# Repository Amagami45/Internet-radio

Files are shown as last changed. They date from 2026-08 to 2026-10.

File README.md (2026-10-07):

# Internet-radio

This project is about building an internet radio receiver which will change the audio output to analog, which will be transferred to an old FM radio (AIWA). From the radio, audio will come out to connected speakers.

## Why?

I have an old Aiwa, which can do only FM and AM frequencies, and most radio stations start to turn to DAB+ signal. So that's the main reason why I chose building this internet radio receiver. Also, I can listen to foreign countries' radio stations.

## Technical specifications

It's powered by a USB-C 16-pin connector (5V). Then it's reduced to 3.3V by AMS1117 regulator. Most parts use 3.3V logic.

### Display
* 2.8" SPI TFT display (ILI9341 controller, 240x320). Connected via cables to the PCB.

### Buttons & Controls
I used Cherry MX switches and a rotary encoder:
* Reset button
* Sleep / ON button
* Up button
* Down button
* Rotary encoder – Volume up / Volume down
* Rotary encoder button – Sound off (Mute)

### Audio output
It's done by PCM5102A DAC chip (I2S audio interface) and 2 RCA cinches (Stereo Left/Right), which connect directly to AIWA AUX input.

## BOM (Bill of Materials)

* ESP32-WROOM-32 (with Bluetooth and Wi-Fi)
* PCM5102A DAC board/chip
* 2.8" SPI TFT Display (ILI9341)
* USB-C 16-pin connector (Type-C)
* AMS1117 3.3V LDO regulator
* Dual horizontal RCA cinch connector
* Cherry MX mechanical switches
* Rotary encoder
* 0603 SMD capacitors and resistors

## Schematics & PCB Design

I used KiCad for that (2-layer board design). Display will be connected by cables, that's why it is designed like it is. 

Snímek obrazovky 2026-08-31 152727
Snímek obrazovky 2026-08-17 105338

## 3D PCB & Case Renders

* 3D PCB export (.STEP) is generated from KiCad.
* All other parts and enclosure case are modeled in Fusion 360.

Snímek obrazovky 2026-08-31 153812
Snímek obrazovky 2026-08-31 153729
Snímek obrazovky 2026-09-01 002420

## 3D Printing Settings

* **Material:** PETG (recommended) or PLA
* **Layer Height:** 0.2 mm
* **Infill:** 15–20% (Gyroid or Grid)
* **Supports:** Needed only for RCA and USB-C cutouts on the rear panel

## Assembly Guide

### 1. PCB Assembly & Soldering
1. **SMD Components First:** Solder the small SMD parts first (AMS1117 regulator, 0603 capacitors/resistors, USB-C connector, and PCM5102A DAC).
2. **ESP32 Module:** Align and solder the ESP32-WROOM-32 module onto the board.
3. **Through-Hole Parts (THT):** Solder the Cherry MX switches, rotary encoder, and dual RCA cinch connector.

### 2. Display Wiring
* Connect the 2.8" ILI9341 TFT display to the PCB header using cables according to the KiCad schematic (VCC, GND, CS, RESET, DC, SDI/MOSI, SCK, LED).

### 3. Firmware Flashing
1. Connect the board to your PC via USB-C.
2. Flash **YoRadio** firmware using PlatformIO / Arduino IDE / Esptool.
3. Configure your GPIO pin mappings for the display, I2S DAC, rotary encoder, and Cherry MX buttons in `myoptions.h`.
4. Connect to the radio's Wi-Fi Access Point to set up your home Wi-Fi credentials and station playlist.

### 4. Enclosure Assembly
1. 3D print the case parts designed in Fusion 360.
2. Mount the 2.8" TFT display into the front panel slot.
3. Secure the PCB inside the main case using small M2/M3 screws.
4. Press keycaps onto the Cherry MX switches and attach the knob to the rotary encoder.
5. Close the 3D-printed enclosure.

### 5. Hooking up to AIWA
1. Connect an RCA stereo audio cable from the radio's cinch connectors to the **AUX / Line In** on your AIWA system.
2. Plug in a standard 5V USB-C power source.
3. Turn on AIWA, switch mode to AUX, select your favorite station, and enjoy!

# Pinout & Connections

## 1. ILI9341 Display (U4)
| ILI9341 Display | ESP32 (U1) / Power | Note |
| :--- | :--- | :--- |
| **VCC** | +3.3V | Logic / Display Power |
| **GND** | GND | Ground |
| **CS** | **IO0** (DISP_CS) | Display Chip Select |
| **D/C** | **IO16** (D/C) | Data / Command |
| **MOSI** | **IO23** | SPI MOSI |
| **MISO** | **IO19** | SPI MISO |
| **SCK** | **IO18** | SPI Clock |
| **LED** | **IO17** (LED) | Backlight Control |
| **RESET** | **RESET** (via D/C / RESET network) | Display Reset |

---

## 2. Micro SD Card Slot (J2)
| Micro SD Slot | Power Source / ESP32 (U1) | Note |
| :--- | :--- | :--- |
| **VDD (Pin 4)** | +3.3V | SD Card Power |
| **GND (Pin 3, 6)** | GND | Ground |
| **DAT3/CD (Pin 2)** | **IO12** (SD_CS) / **IO5** | Chip Select (10kΩ pull-up R6) |
| **CMD (Pin 3)** | **IO23** | SPI MOSI |
| **CLK (Pin 5)** | **IO18** | SPI SCK |
| **DAT0 (Pin 7)** | **IO19** | SPI MISO (10kΩ pull-up R16) |
| **DAT1 (Pin 8)** | — | 10kΩ pull-up R17 to +3.3V |
| **DAT2 (Pin 1)** | — | 10kΩ pull-up R15 to +3.3V |

---

## 3. Audio DAC PCM5102 (U3)
| PCM5102 Pin | ESP32 (U1) / Power | Function / Note |
| :--- | :--- | :--- |
| **CPVDD, DVDD, AVDD** | +3.3V | DAC Power (filtered by C3, C4, C5) |
| **GND, AGND, DGND** | GND | Ground |
| **LRCK (Pin 15)** | **IO25** | I2S Word Select (LRCK) |
| **DIN (Pin 14)** | **IO27** | I2S Data Input |
| **BCK (Pin 13)** | **IO26** | I2S Bit Clock |
| **SCK (Pin 12)** | GND | System Clock (connected to GND) |
| **OUTL (Pin 6)** | C3 / R5 / J3A Output | Left Channel Audio Output (Coaxial J3A) |
| **OUTR (Pin 7)** | C1 / R4 / J3B Output | Right Channel Audio Output (Coaxial J3B) |

---

## 4. Rotary Encoder with Button (SW1)
| Encoder Pin | ESP32 (U1) / Power | Note |
| :--- | :--- | :--- |
| **A (Pin A)** | **IO32** | Encoder Phase A |
| **B (Pin B)** | **IO33** | Encoder Phase B |
| **C (Pin C)** | GND | Encoder Common Pin |
| **S1 (Pin S1)** | **IO18** | Encoder Switch / Button |
| **S2 (Pin S2)** | GND | Encoder Switch Other Side |

---

## 5. Control Buttons
| Button | ESP32 Pin | Connection |
| :--- | :--- | :--- |
| **SW2** | **IO23** / **IO5** | Pushbutton to GND (switches to GND) |
| **SW3** | **IO22** | Pushbutton to GND (switches to GND) |
| **SW5** | **IO15** (via 1kΩ R12) | Pushbutton to GND (switches to GND) |
| **SW6** | **EN** | RESET button (switches EN to GND) |
| **SW7** | **IO3 (RXD)** (via R8/R11) | User / Boot Button |

---

## 6. USB-C UART Converter (CP2102N - U5) & Power Supply
* **USB Connector (J1):** Supplies VBUS (+5V) to the **AMS1117-3.3 (U2)** regulator, which generates the main **+3.3V** power supply for the entire circuit.
* **Converter CP2102N (U5):**
  * **TXD (Pin 21)** $\rightarrow$ **IO3 (RXD)** on ESP32 (via 1kΩ resistor R11)
  * **RXD (Pin 20)** $\leftarrow$ **IO1 (TXD)** from ESP32 (via 1kΩ resistor R12)
  * **DTR / RTS** $\rightarrow$ Connected to **Q1/Q2 (BC847)** transistors for automatic programming mode switching (EN and IO0).

## Software & Firmware

The radio firmware is built on the **ESP32** platform (Arduino IDE / PlatformIO) and ensures smooth reception of internet streams via Wi-Fi, their decoding, and digital audio processing.

### Key Features
* **Wi-Fi Connectivity:** Automatic connection to the configured network at system startup.
* **Audio Streaming (I2S):** Direct digital audio data transmission over the I2S interface to the PCM5102 DAC for high sound quality.
* **Station Management:** Pre-configured playlist of domestic and foreign radio stations (MP3/AAC streams) with sequential switching.
* **Volume Control:** Fine digital volume control directly inside the audio decoder.

### Control Mapping
Control is handled via buttons and a rotary encoder connected to the ESP32 GPIO pins:
* **SW3 (BTN_UP):** Switch to the next radio station.
* **SW2 (BTN_DOWN):** Switch to the previous radio station.
* **SW5 (BTN_LEFT):** Volume down.
* **SW7 (BTN_RIGHT):** Volume up.
* **SW1 (Encoder):** Menu navigation and additional features.

### Included Libraries
* **WiFi.h** – Network connection and wireless management.
* **ESP32-audioI2S** – Audio decoding and I2S communication handling.

## Credits & Acknowledgments

* Firmware powered by **ESP32-audioI2S** and **WiFi.h** library.

## License

This work is under GNU license. More info in LICENSE file.

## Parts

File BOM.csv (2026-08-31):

No | Quantity | Comment | Designator | Footprint | Value | Manufacturer Part | Manufacturer | Supplier Part | Supplier | Price | URL
1 | 1 | ESP32 Wi-Fi/BT Module | U1 | RF_Module:ESP32-WROOM-32 | ESP32-WROOM-32 | ESP32-WROOM-32E-N4 | Espressif | C473012 | LCSC | 2.85$ | https://www.lcsc.com/product-detail/WiFi-Modules_Espressif-Systems-ESP32-WROOM-32E-N4_C473012.html
2 | 1 | 3.3V LDO Voltage Regulator | U2 | Package_TO_SOT_SMD:SOT-223-3_TabPin2 | AMS1117-3.3 | AMS1117-3.3 | AMS | C6186 | LCSC | 0.12$ | https://www.lcsc.com/product-detail/Linear-Voltage-Regulators-LDO_AMS-Advanced-Monolithic-Systems-AMS1117-3-3_C6186.html
3 | 1 | I2S Audio DAC Chip | U3 | Package_SO:TSSOP-20_4.4x6.5mm_P0.65mm | PCM5102A | PCM5102AIPWR | Texas Instruments | C67139 | LCSC | 1.80$ | https://www.lcsc.com/product-detail/Audio-Processors-DACS-MDS_Texas-Instruments-PCM5102AIPWR_C67139.html
4 | 1 | TFT Display Screen | U4 | Display:CR2013-MI2120 | CR2013-MI2120 | CR2013-MI2120 | Generic | Custom | AliExpress | 2.50$ | http://pan.baidu.com/s/11Y990
5 | 1 | USB-to-UART Bridge | U5 | Package_DFN_QFN:QFN-24-1EP_4x4mm_P0.5mm_EP2.6x2.6mm | CP2102N-Axx-xQFN24 | CP2102N-A02-GQFN24R | Silicon Labs | C141118 | LCSC | 1.20$ | https://www.lcsc.com/product-detail/USB-IC_Silicon-Labs-CP2102N-A02-GQFN24R_C141118.html
6 | 2 | NPN Transistor | Q1, Q2 | Package_TO_SOT_SMD:SOT-23 | BC847 | BC847B | Nexperia | C2131 | LCSC | 0.02$ | https://www.lcsc.com/product-detail/Bipolar-Transistors-BJT_Nexperia-BC847B-215_C2131.html
7 | 1 | USB-C Receptacle 16P | J1 | Connector_USB:USB_C_Receptacle_HRO_TYPE-C-31-M-12 | TYPE-C 16PIN 2MD(073) | TYPE-C 16PIN 2MD(073) | SHOU HAN | C2765186 | LCSC | 0.08$ | https://www.lcsc.com/product-detail/C2765186.html
8 | 1 | Micro SD Card Slot | J2 | Connector_Card:microSD_HC_Hirose_DM3AT-SF-PEJM5 | Micro_SD_Card | DM3AT-SF-PEJM5 | Hirose | C114219 | LCSC | 0.40$ | https://www.we-online.com/components/products/datasheet/693072010801.pdf
9 | 1 | 4-Pin Header (Audio Out) | J3 | Connector_PinHeader_2.54mm:PinHeader_1x04_P2.54mm_Vertical | Conn_Coaxial_x2_Isolated | Header-1x4P-2.54 | Generic | C22548 | LCSC | 0.05$ | https://www.lcsc.com/product-detail/Pin-Header-Female-Header_C22548.html
10 | 1 | Rotary Encoder with Switch | SW1 | Rotary_Encoder:RotaryEncoder_Alps_EC11E-Switch_Vertical_H20mm | RotaryEncoder_Switch | EC11E1224404 | ALPS | C25243 | LCSC | 0.50$ | https://www.lcsc.com/product-detail/Encoders_ALPS-EC11E1224404_C25243.html
11 | 5 | Cherry MX Push Switch | SW2, SW3, SW5, SW6, SW7 | Button_Switch_Keyboard:SW_Cherry_MX_1.00u_PCB | SW_Push | MX-1.0U | Cherry | Custom | AliExpress | 0.25$ | https://www.aliexpress.com
12 | 2 | 5.1k Resistor 0603 | R1, R2 | Resistor_SMD:R_0603_1608Metric | 5.1k | 0603WAF5101T5E | UNI-ROYAL | C23186 | LCSC | 0.005$ | https://www.lcsc.com/product-detail/C23186.html
13 | 10 | 10k Resistor 0603 | R3, R6, R7, R8, R10, R13, R14, R15, R16, R17 | Resistor_SMD:R_0603_1608Metric | 10k | 0603WAF1002T5E | UNI-ROYAL | C25804 | LCSC | 0.005$ | https://www.lcsc.com/product-detail/Chip-Resistor-Surface-Mount_UNI-ROYAL-Uni-Royal-Elec-0603WAF1002T5E_C25804.html
14 | 2 | 470R Resistor 0603 | R4, R5 | Resistor_SMD:R_0603_1608Metric | 470R | 0603WAF4700T5E | UNI-ROYAL | C23179 | LCSC | 0.005$ | https://www.lcsc.com/product-detail/Chip-Resistor-Surface-Mount_UNI-ROYAL-Uni-Royal-Elec-0603WAF4700T5E_C23179.html
15 | 1 | 4.7k Resistor 0603 | R9 | Resistor_SMD:R_0603_1608Metric | 4.7k | 0603WAF4701T5E | UNI-ROYAL | C23162 | LCSC | 0.005$ | https://www.lcsc.com/product-detail/Chip-Resistor-Surface-Mount_UNI-ROYAL-Uni-Royal-Elec-0603WAF4701T5E_C23162.html
16 | 2 | 1k Resistor 0603 | R11, R12 | Resistor_SMD:R_0603_1608Metric | 1k | 0603WAF1001T5E | UNI-ROYAL | C21190 | LCSC | 0.005$ | https://www.lcsc.com/product-detail/Chip-Resistor-Surface-Mount_UNI-ROYAL-Uni-Royal-Elec-0603WAF1001T5E_C21190.html
17 | 2 | 2.2uF Capacitor 0603 | C1, C6 | Capacitor_SMD:C_0603_1608Metric | 2.2uF | CL10A225KP8NNNC | SAMSUNG | C15858 | LCSC | 0.01$ | https://www.lcsc.com/product-detail/Multilayer-Ceramic-Capacitors-MLCC-SMD-SMT_SAMSUNG-CL10A225KP8NNNC_C15858.html
18 | 2 | 1uF Capacitor 0603 | C2, C7 | Capacitor_SMD:C_0603_1608Metric | 1uF | CL10A105KB8NNNC | SAMSUNG | C15849 | LCSC | 0.01$ | https://www.lcsc.com/product-detail/C15849.html
19 | 9 | 100nF Capacitor 0603 | C3, C4, C5, C9, C11, C12, C13, C19, C20 | Capacitor_SMD:C_0603_1608Metric | 100nF | CL10B104KB8NNNC | SAMSUNG | C14663 | LCSC | 0.005$ | https://www.lcsc.com/product-detail/Multilayer-Ceramic-Capacitors-MLCC-SMD-SMT_SAMSUNG-CL10B104KB8NNNC_C14663.html
20 | 2 | 10uF Capacitor 0603 | C8, C10 | Capacitor_SMD:C_0603_1608Metric | 10uF | CL10A106MO8NNNC | SAMSUNG | C19702 | LCSC | 0.02$ | https://www.lcsc.com/product-detail/Multilayer-Ceramic-Capacitors-MLCC-SMD-SMT_SAMSUNG-CL10A106MO8NNNC_C19702.html
21 | 2 | 2.2nF Capacitor 0603 | C14, C15 | Capacitor_SMD:C_0603_1608Metric | 2.2nF | CL10B222KB8NNNC | SAMSUNG | C1600 | LCSC | 0.005$ | https://www.lcsc.com/product-detail/Multilayer-Ceramic-Capacitors-MLCC-SMD-SMT_SAMSUNG-CL10B222KB8NNNC_C1600.html
22 | 2 | 4.7uF Capacitor 0603 | C18, C21 | Capacitor_SMD:C_0603_1608Metric | 4.7uF | CL10A475KP8NNNC | SAMSUNG | C19666 | LCSC | 0.01$ | https://www.lcsc.com/product-detail/Multilayer-Ceramic-Capacitors-MLCC-SMD-SMT_SAMSUNG-CL10A475KP8NNNC_C19666.html

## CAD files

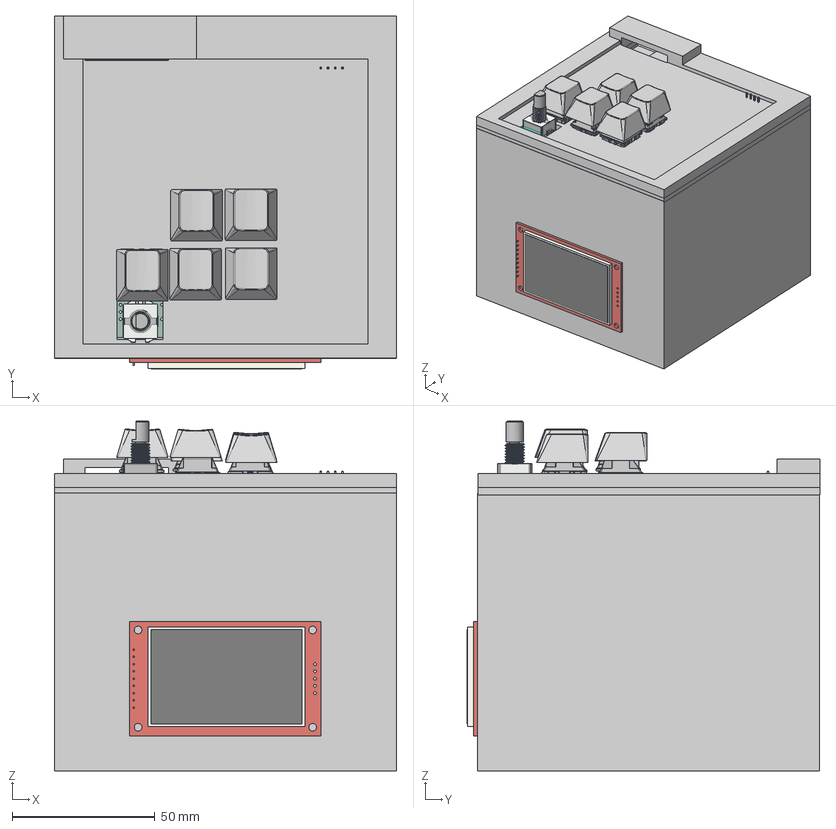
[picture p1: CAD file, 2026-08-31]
3d aiwa model 1.step
120.0 x 123.8 x 122.7 mm

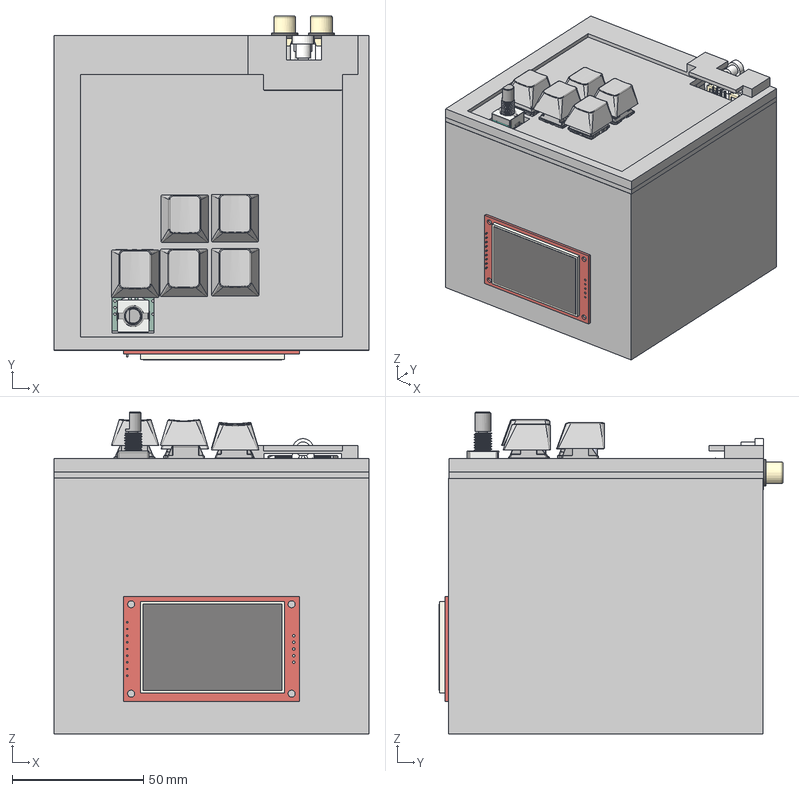
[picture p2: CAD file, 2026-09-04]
3d aiwa/3d aiwa model.step
120.0 x 131.2 x 122.7 mm

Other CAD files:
3d aiwa/3d aiwa model.f3z
3d aiwa/3d aiwa model.stl
3d aiwa/Aiwa up.f3d
3d aiwa/Aiwa.f3d

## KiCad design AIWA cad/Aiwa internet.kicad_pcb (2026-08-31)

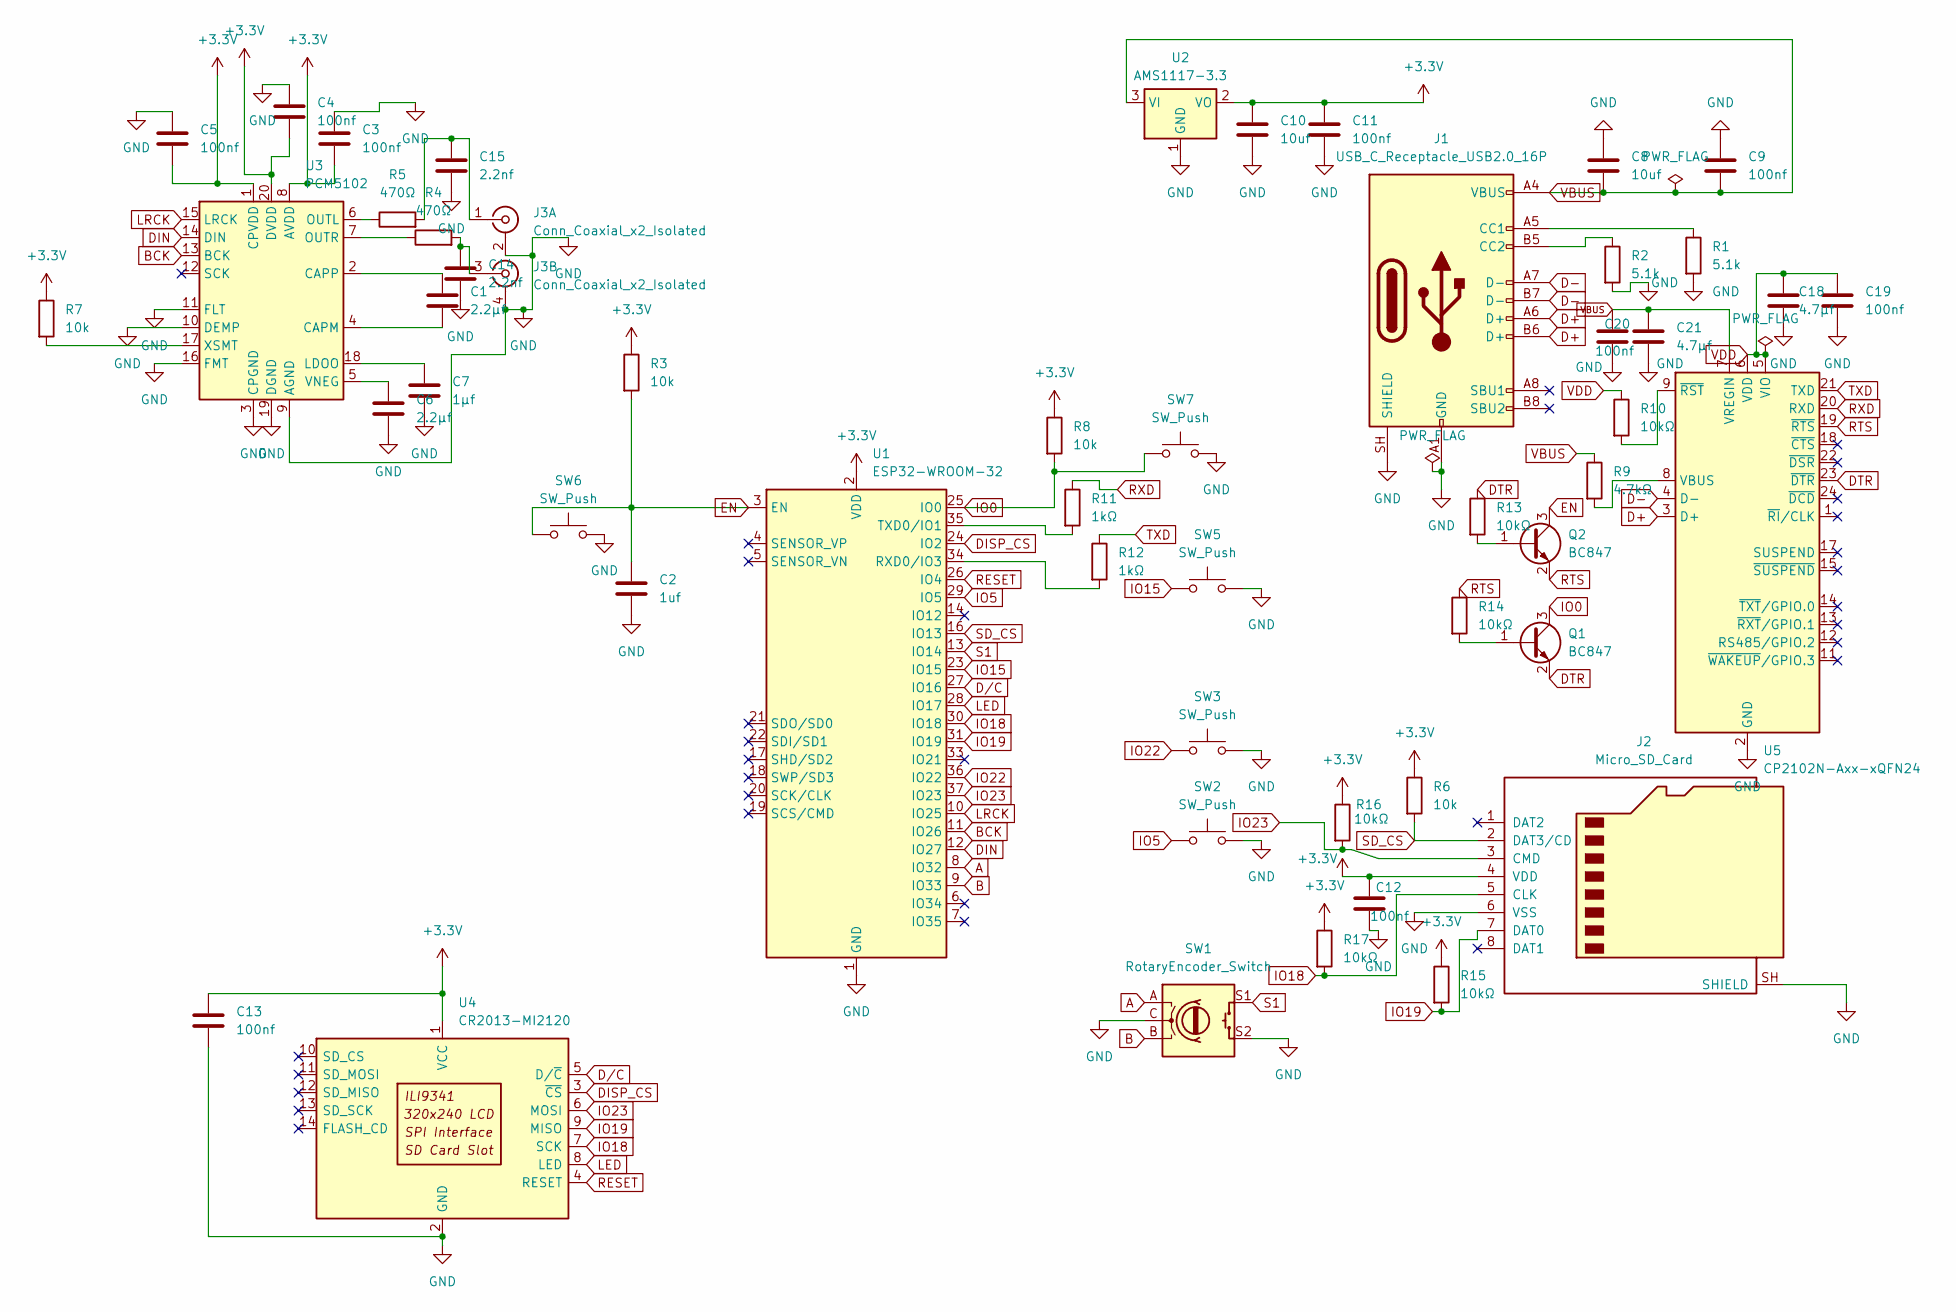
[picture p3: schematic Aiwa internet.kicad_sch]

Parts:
C1, C6: 2.2μf; C_0603_1608Metric
C2: 1uf; C_0603_1608Metric
C3, C4, C5, C9, C11, C12, C13, C19, C20: 100nf; C_0603_1608Metric
C7: 1μf; C_0603_1608Metric
C8, C10: 10uf; C_0603_1608Metric
C14, C15: 2.2nf; C_0603_1608Metric
C18, C21: 4.7µf; C_0603_1608Metric
J1: USB_C_Receptacle_USB2.0_16P; USB_C_Receptacle_HRO_TYPE-C-31-M-12
J2: Micro_SD_Card; microSD_HC_Hirose_DM3AT-SF-PEJM5
J3: Conn_Coaxial_x2_Isolated; PinHeader_1x04_P2.54mm_Vertical
Q1, Q2: BC847; SOT-23
R1, R2: 5.1k; R_0603_1608Metric
R3, R6, R7, R8: 10k; R_0603_1608Metric
R4, R5: 470Ω; R_0603_1608Metric
R9: 4.7kΩ; R_0603_1608Metric
R10, R13, R14, R15, R16, R17: 10kΩ; R_0603_1608Metric
R11, R12: 1kΩ; R_0603_1608Metric
SW1: RotaryEncoder_Switch; RotaryEncoder_Alps_EC11E-Switch_Vertical_H20mm
SW2, SW3, SW5, SW6, SW7: SW_Push; SW_Cherry_MX_1.00u_PCB
U1: ESP32-WROOM-32
U2: AMS1117-3.3; SOT-223-3_TabPin2
U3: PCM5102; TSSOP-20_4.4x6.5mm_P0.65mm
U4: CR2013-MI2120
U5: CP2102N-Axx-xQFN24; QFN-24-1EP_4x4mm_P0.5mm_EP2.6x2.6mm

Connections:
+3.3V: C3.2, C4.2, C5.2, C10.1, C11.1, C12.1, C13.1, J2.4 (VDD), R3.1, R6.1, R7.1, R8.1, R15.1, R16.1, R17.1, U1.2 (VDD), U2.2 (VO), U3.1 (CPVDD), U3.8 (AVDD), U3.20 (DVDD), U4.1 (VCC)
A: SW1.A, U1.8 (IO32)
B: SW1.B, U1.9 (IO33)
BCK: U1.11 (IO26), U3.13 (BCK)
D+: J1.A6 (D+), J1.B6 (D+), U5.3 (D+)
D-: J1.A7 (D-), J1.B7 (D-), U5.4 (D-)
DIN: U1.12 (IO27), U3.14 (DIN)
DISP_CS: U1.24 (IO2), U4.3 (~CS)
DTR: Q1.2 (E), R13.1, U5.23 (~DTR)
D/C: U1.27 (IO16), U4.5 (D/~C)
EN: C2.1, Q2.3 (C), R3.2, SW6.1, U1.3 (EN)
GND: C2.2, C3.1, C4.1, C5.1, C6.2, C7.2, C8.1, C9.1, C10.2, C11.2, C12.2, C13.2, C14.2, C15.2, C18.2, C19.2, C20.2, C21.2, J1.A1 (GND), J1.A12 (GND), J1.B1 (GND), J1.B12 (GND), J1.SH (SHIELD), J2.6 (VSS), J2.SH (SHIELD), J3.2 (Ext1), J3.4 (Ext2), R1.2, R2.2, SW1.C, SW1.S2, SW2.2, SW3.2, SW5.2, SW6.2, SW7.2, U1.1 (GND), U1.15 (GND), U1.38 (GND), U1.39 (GND), U2.1 (GND), U3.3 (CPGND), U3.9 (AGND), U3.10 (DEMP), U3.11 (FLT), U3.16 (FMT), U3.19 (DGND), U4.2 (GND), U5.2 (GND), U5.25 (GND)
IO0: Q1.3 (C), R8.2, SW7.1, U1.25 (IO0)
IO5: SW2.1, U1.29 (IO5)
IO15: SW5.1, U1.23 (IO15)
IO18: J2.5 (CLK), R17.2, U1.30 (IO18), U4.7 (SCK)
IO19: J2.7 (DAT0), R15.2, U1.31 (IO19), U4.9 (MISO)
IO22: SW3.1, U1.36 (IO22)
IO23: J2.3 (CMD), R16.2, U1.37 (IO23), U4.6 (MOSI)
LED: U1.28 (IO17), U4.8 (LED)
LRCK: U1.10 (IO25), U3.15 (LRCK)
unnamed: J1.A5 (CC1), R1.1
unnamed: J1.B5 (CC2), R2.1
unnamed: C15.1, J3.1 (In1), R5.2
unnamed: C14.1, J3.3 (In2), R4.2
unnamed: Q1.1 (B), R14.2
unnamed: Q2.1 (B), R13.2
unnamed: R12.2, U1.34 (RXD0/IO3)
unnamed: R11.2, U1.35 (TXD0/IO1)
unnamed: C1.2, U3.4 (CAPM)
unnamed: C1.1, U3.2 (CAPP)
unnamed: C7.1, U3.18 (LDOO)
unnamed: R5.1, U3.6 (OUTL)
unnamed: R4.1, U3.7 (OUTR)
unnamed: C6.1, U3.5 (VNEG)
unnamed: R7.2, U3.17 (XSMT)
unnamed: R9.2, U5.8 (VBUS)
unnamed: R10.2, U5.9 (~RST)
RESET: U1.26 (IO4), U4.4 (RESET)
RTS: Q2.2 (E), R14.1, U5.19 (~RTS)
RXD: R11.1, U5.20 (RXD)
S1: SW1.S1, U1.13 (IO14)
SD_CS: J2.2 (DAT3/CD), R6.2, U1.16 (IO13)
TXD: R12.1, U5.21 (TXD)
VBUS: C8.2, C9.2, C20.1, C21.1, J1.A4 (VBUS), J1.A9 (VBUS), J1.B4 (VBUS), J1.B9 (VBUS), R9.1, U2.3 (VI), U5.7 (VREGIN)
VDD: C18.1, C19.1, R10.1, U5.5 (VIO), U5.6 (VDD)

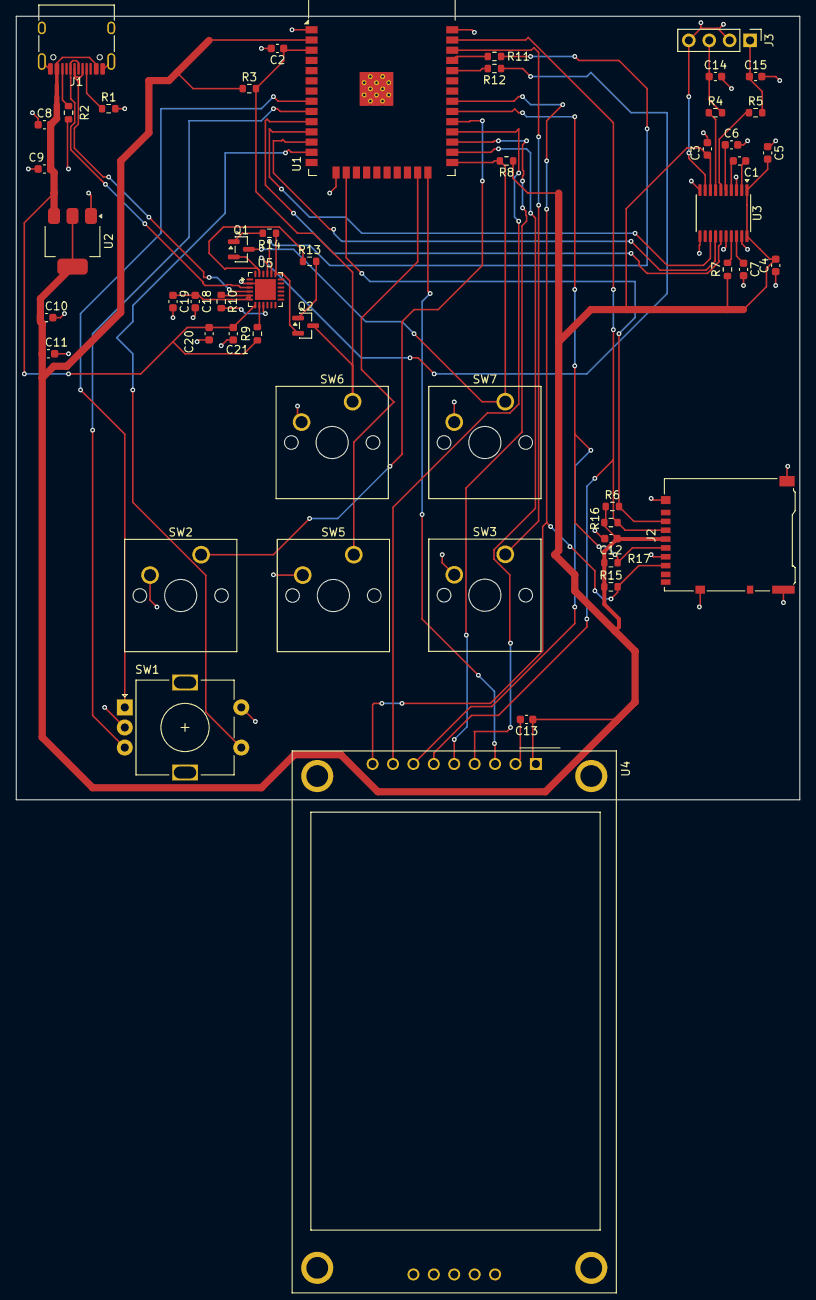
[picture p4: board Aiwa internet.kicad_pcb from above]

Board: 2 copper layers, 97.5 x 97.5 mm, 52 parts (0 on the bottom side), 46 nets.

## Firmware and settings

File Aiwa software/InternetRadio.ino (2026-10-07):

#include <Arduino.h>
#include <WiFi.h>
#include "Audio.h"
#include "myprofile.h"


const char* ssid = "YOUR_WIFI_NAME";
const char* password = "YOUR_WIFI_PASSWORD";


const char* stations[] = {

  "http://icecast3.play.cz/evropa2-128.mp3",
  "http://icecast1.play.cz/frekvence1-128.mp3",
  "http://icecast1.play.cz/impuls128.mp3",
  "http://ice.abradio.cz/kiss128.mp3",
  "http://icecast1.play.cz/radioblanik128.mp3",
  

  "http://ice.abradio.cz/radiozurnal128.mp3",
  "http://icecast7.play.cz/croplus128.mp3",
  

  "http://icecast1.play.cz/rockradio128.mp3",
  "http://icecast1.play.cz/beat128.mp3",
  

  "http://icecast1.play.cz/dance-radio128.mp3",
  "http://icecast1.play.cz/spin128.mp3",
  

  "http://ice.abradio.cz/fajn128.mp3",
  "http://icecast1.play.cz/crojazz128.mp3",
  

  "http://stream.srg-ssr.ch/m/rsj/mp3_128", 
  "http://stream.nonstopoldies.at:8000/oldies"
};

const char* stationNames[] = {
  "Evropa 2",
  "Frekvence 1",
  "Radio Impuls",
  "Radio Kiss",
  "Radio Blanik",
  "CRo Radiozurnal",
  "CRo Plus",
  "Rock Radio",
  "Radio Beat",
  "Dance Radio",
  "Radio Spin",
  "Fajn Radio",
  "CRo Jazz",
  "Swiss Jazz",
  "Nonstop Oldies"
};

int currentStation = 0;
int maxStations = sizeof(stations) / sizeof(stations[0]);
int volume = 12; //(0 - 21)

Audio audio;

void setup() {
  Serial.begin(115200);


  pinMode(BTN_UP, INPUT_PULLUP);
  pinMode(BTN_DOWN, INPUT_PULLUP);
  pinMode(BTN_LEFT, INPUT_PULLUP);
  pinMode(BTN_RIGHT, INPUT_PULLUP);
  pinMode(ENCODER_BTN, INPUT_PULLUP);


  pinMode(BL_PIN, OUTPUT);
  digitalWrite(BL_PIN, HIGH);


  WiFi.begin(ssid, password);
  Serial.print("Pripojovani k WiFi");
  while (WiFi.status() != WL_CONNECTED) {
    delay(500);
    Serial.print(".");
  }
  Serial.println("\nWiFi pripojeno!");


  audio.setPinout(I2S_BCLK, I2S_LRC, I2S_DOUT);
  audio.setVolume(volume);


  audio.connecttohost(stations[currentStation]);
  Serial.print("Hraje stanice: ");
  Serial.println(stationNames[currentStation]);
}

void loop() {

  audio.loop();


  if (digitalRead(BTN_UP) == LOW) { 
    delay(200); 
    currentStation = (currentStation + 1) % maxStations;
    audio.connecttohost(stations[currentStation]);
    Serial.print("Stanice: ");
    Serial.println(stationNames[currentStation]);
  }

  if (digitalRead(BTN_DOWN) == LOW) { 
    delay(200);
    currentStation = (currentStation - 1 + maxStations) % maxStations;
    audio.connecttohost(stations[currentStation]);
    Serial.print("Stanice: ");
    Serial.println(stationNames[currentStation]);
  }

  if (digitalRead(BTN_LEFT) == LOW) {
    delay(150);
    if (volume > 0) volume--;
    audio.setVolume(volume);
    Serial.print("Hlasitost: ");
    Serial.println(volume);
  }

  if (digitalRead(BTN_RIGHT) == LOW) {
    delay(150);
    if (volume < 21) volume++;
    audio.setVolume(volume);
    Serial.print("Hlasitost: ");
    Serial.println(volume);
  }
}


void audio_showstation(const char *info) {
  Serial.print("Stream info: ");
  Serial.println(info);
}

void audio_showstreamtitle(const char *info) {
  Serial.print("Hraje pisnicka: ");
  Serial.println(info);
}

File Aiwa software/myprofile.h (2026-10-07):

#ifndef myprofile_h
#define myprofile_h

#define DSP_MODEL     DSP_ILI9341
#define CS_PIN        0
#define DC_PIN        16
#define RST_PIN       -1
#define BL_PIN        17

#define I2S_DOUT      27
#define I2S_BCLK      26
#define I2S_LRC       25

#define ENCODER_PIN_A 32
#define ENCODER_PIN_B 33
#define ENCODER_BTN   18

#define BTN_UP        22
#define BTN_DOWN      5
#define BTN_LEFT      15
#define BTN_RIGHT     3

#define SD_CS_PIN     12

#endif

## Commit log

2026-07-26 Add BOM with components and pricing information
    Added bill of materials for the project with components, quantities, and pricing.
    [BOM.csv]
2026-07-26 Modify ESP32-WROOM-32 supplier and price details
    Updated supplier information and price for ESP32-WROOM-32 module.
    [BOM.csv]
2026-07-26 Fix formatting issue in BOM.csv
    [BOM.csv]
2026-07-26 Update BOM.csv with new component details
    [BOM.csv]
2026-07-26 Update BOM.csv to modify component list
    Removed USB-A and MicroUSB connectors, pin headers, resistors, capacitors, and AMS1117-3.3 regulator from BOM. Added RCA-RCA cable entry.
    [BOM.csv]
2026-07-26 Revise BOM.csv with corrected part information
    Updated part details including manufacturer and price format.
    [BOM.csv]
2026-07-30 Update BOM.csv with new components and details
    Added new components to the BOM including capacitors, resistors, connectors, and screws with updated pricing and URLs.
    [BOM.csv]
2026-07-30 Modify BOM.csv with updated supplier details
    Updated supplier information for M2x6 Screws, 3D Printed Case, and PCB Board.
    [BOM.csv]
2026-07-30 Remove duplicate entries for 3D Printed Case and PCB Board
    [BOM.csv]
2026-07-30 Update BOM.csv with new components and quantities
    Added new components including ESP32-WROOM-32 module and GY-PCM5102 I2S DAC module.
    [BOM.csv]
2026-07-31 Adjust quantities and remove duplicates in BOM
    Updated quantities for several components and fixed duplicate entries.
    [BOM.csv]
2026-07-31 Reorder and update components in BOM.csv
    [BOM.csv]
2026-07-31 Update quantity for TYPE-C 16PIN 2MD(073) component
    [BOM.csv]
2026-08-06 Add AMS1117 and Micro SD card slot modules to BOM
    [BOM.csv]
2026-08-28 Update README with technical specifications and components
    Added technical specifications and display/button details.
2026-08-28 Add BOM section to README
2026-08-29 Update README with button functions and audio output
    Added additional button functionalities and clarified audio output details.
2026-08-29 Fix button list formatting in README
    Corrected numbering format for button list in README.
2026-08-31 Update BOM with new components and specifications
    Added new components including ESP32 module, voltage regulators, and various capacitors and resistors to BOM.
    [BOM.csv]
2026-08-31 Add assembly guide to README
    Added an assembly guide for PCB assembly, display wiring, firmware flashing, enclosure assembly, and connecting to AIWA.
2026-08-31 Update README with 3D printing settings and credits
    Added 3D printing settings and credits section to README.
2026-09-07 Update README with button preferences and firmware details
2026-10-07 Update README with component pinout and connections
    Added detailed pinout and connection information for various components including ILI9341 display, Micro SD card slot, audio DAC, rotary encoder, control buttons, and USB-C UART converter.
